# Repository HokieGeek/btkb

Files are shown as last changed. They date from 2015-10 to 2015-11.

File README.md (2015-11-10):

# btkb

I have a fantastic Pok3r mech that, annoyingly, uses a cable to connect to my computer. I am building a module that includes a decent battery and bluetooth modem to replace the cable.

## Prototype
Current

# Schematics
## Power module
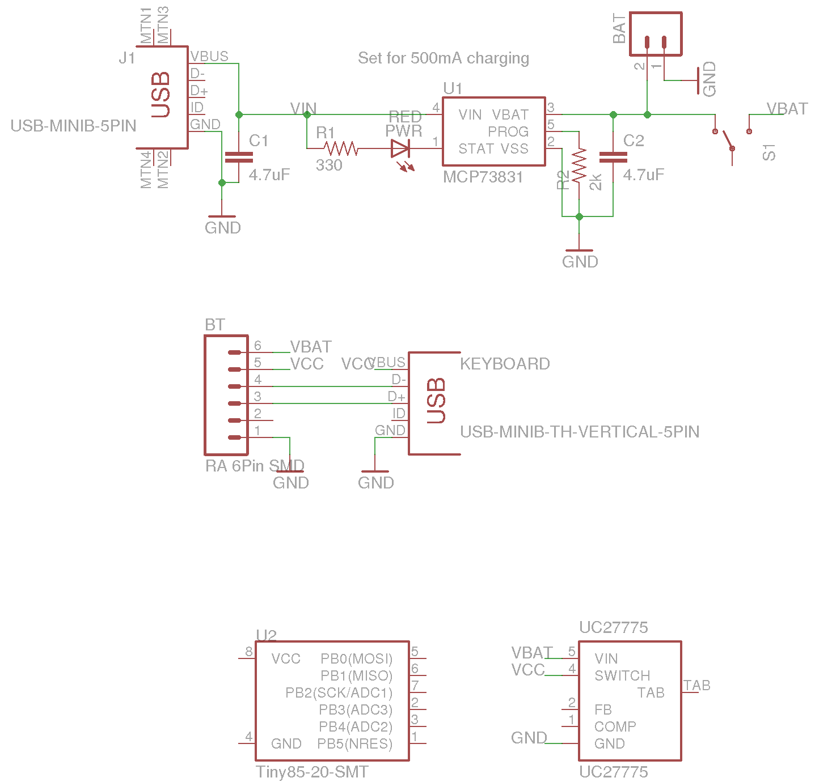
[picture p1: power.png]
Power module schematics

## Bluetooth module
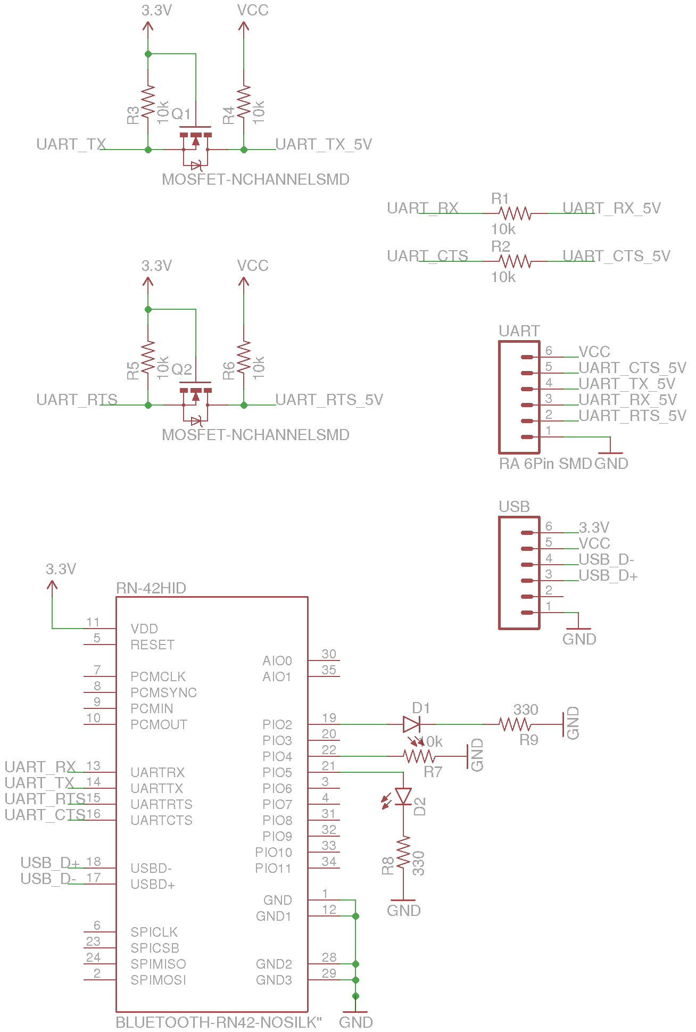
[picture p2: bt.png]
Bluetooth module schematics


# Board
## Power module
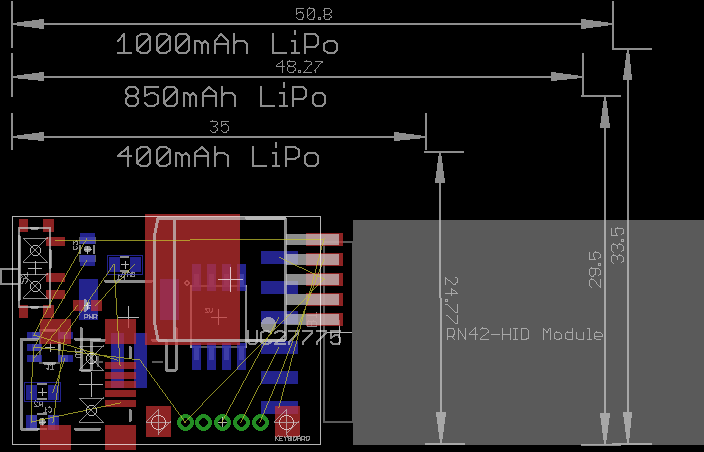
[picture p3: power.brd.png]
Power module board

## Bluetooth Module
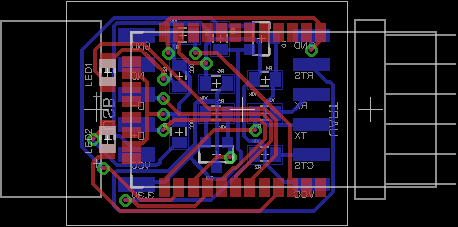
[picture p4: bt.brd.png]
Bluetooth module board


# Parts list
[Mouser project](https://www.mouser.com/ProjectManager/ProjectDetail.aspx?ProjectGUID=d7660f5c-4cd6-4143-9f81-287e7d12060d)

## ICs
- [RN-42 HID](http://www.sparkfun.com/datasheets/Wireless/Bluetooth/rn-42-ds.pdf) - Bluetooth modem with HID firmware
- [BSS138](https://www.fairchildsemi.com/datasheets/BS/BSS138.pdf) - MOSFET N-Channel Logic
- [MCP73831T](https://www.sparkfun.com/datasheets/Prototyping/Batteries/MCP73831T.pdf) - Li-Ion battery 4.5V voltage regulator
- [LM25775](http://www.ti.com/lit/ds/symlink/uc2577-adj.pdf) - Adjustable step-up voltage regulator

## Other components

* LEDs
 * 1x Red (data in to BT)
 * 1x Green (data out of BT)
 * Some sort of LED for battery status (TODO)
* Resistors
 * 7x 10 kΩ
 * 1x 2 kΩ
 * 3x 330 Ω
* Capacitors
 * 2x 10 µF (polarized)
 * 2x 4.7 µF
 * 2x 1 µF

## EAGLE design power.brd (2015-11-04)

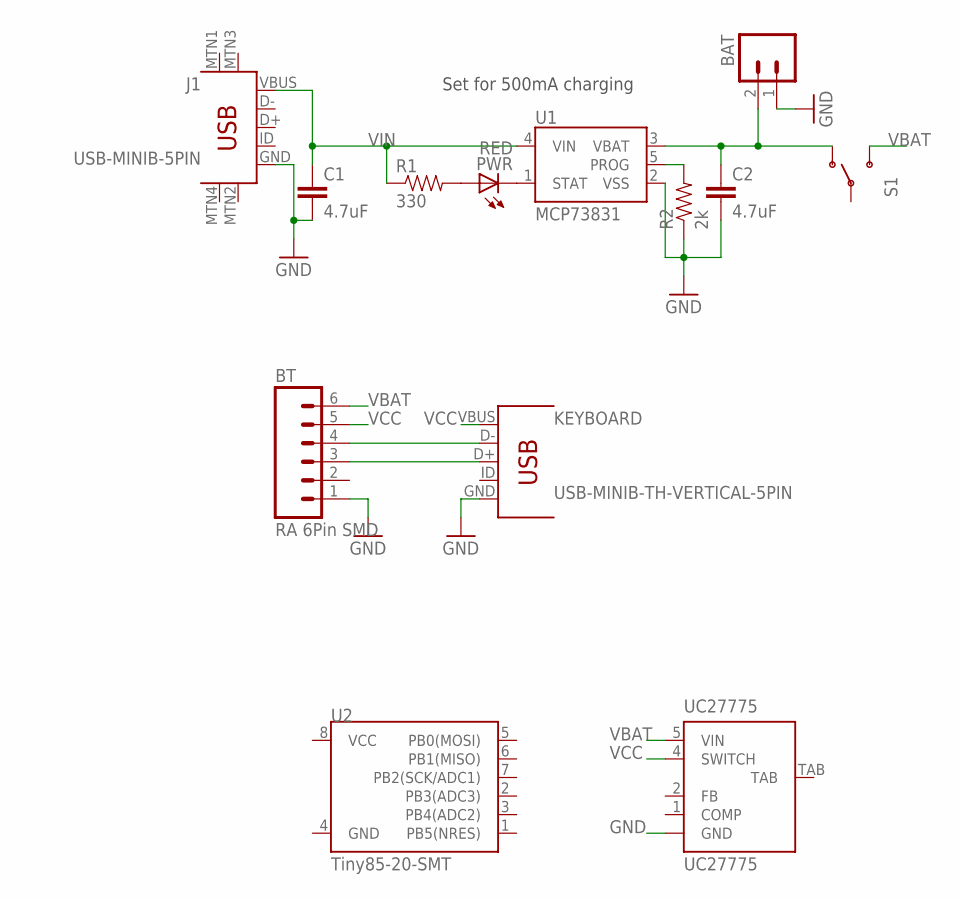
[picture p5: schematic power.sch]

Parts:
BAT: LiPo Battery; JST-2-SMD
BT: RA 6Pin SMD; 1X06-SMD-NOHOLES
C1, C2: 4.7uF; 0805-CAP
J1: USB-MINIB-5PIN; USB-MINIB
KEYBOARD: USB-MINIB-TH-VERTICAL-5PIN; USB-MINIB-TH-VERTICAL
PWR: RED; LED-0603
R1: 330; 0805
R2: 2k; 0805
S1: SWITCH-SPDT-SMD-A; SWITCH-SPST-SMD-A
U1: MCP73831; SOT23-5
U2: Tiny85-20-SMT; SO08-EIAJ
UC27775: UC27775; TO263_5

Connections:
GND: BAT.1, BT.1, C1.2, C2.2, J1.GND, KEYBOARD.GND, R2.1, U1.2 (VSS), UC27775.3 (GND)
unnamed: BT.4, KEYBOARD.D-
unnamed: BT.3, KEYBOARD.D+
unnamed: PWR.A, R1.2
PROG: R2.2, U1.5 (PROG)
STAT: PWR.C, U1.1 (STAT)
VBAT: BT.6, S1.3 (S), UC27775.5 (VIN)
VBAT2: BAT.2, C2.1, S1.1 (O), U1.3 (VBAT)
VCC: BT.5, KEYBOARD.VBUS, UC27775.4 (SWITCH)
VIN: C1.1, J1.VBUS, R1.1, U1.4 (VIN)

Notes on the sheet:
Set for 500mA charging

Board: 2 copper layers, 13 parts (8 on the bottom side), 10 nets, no tracks yet.

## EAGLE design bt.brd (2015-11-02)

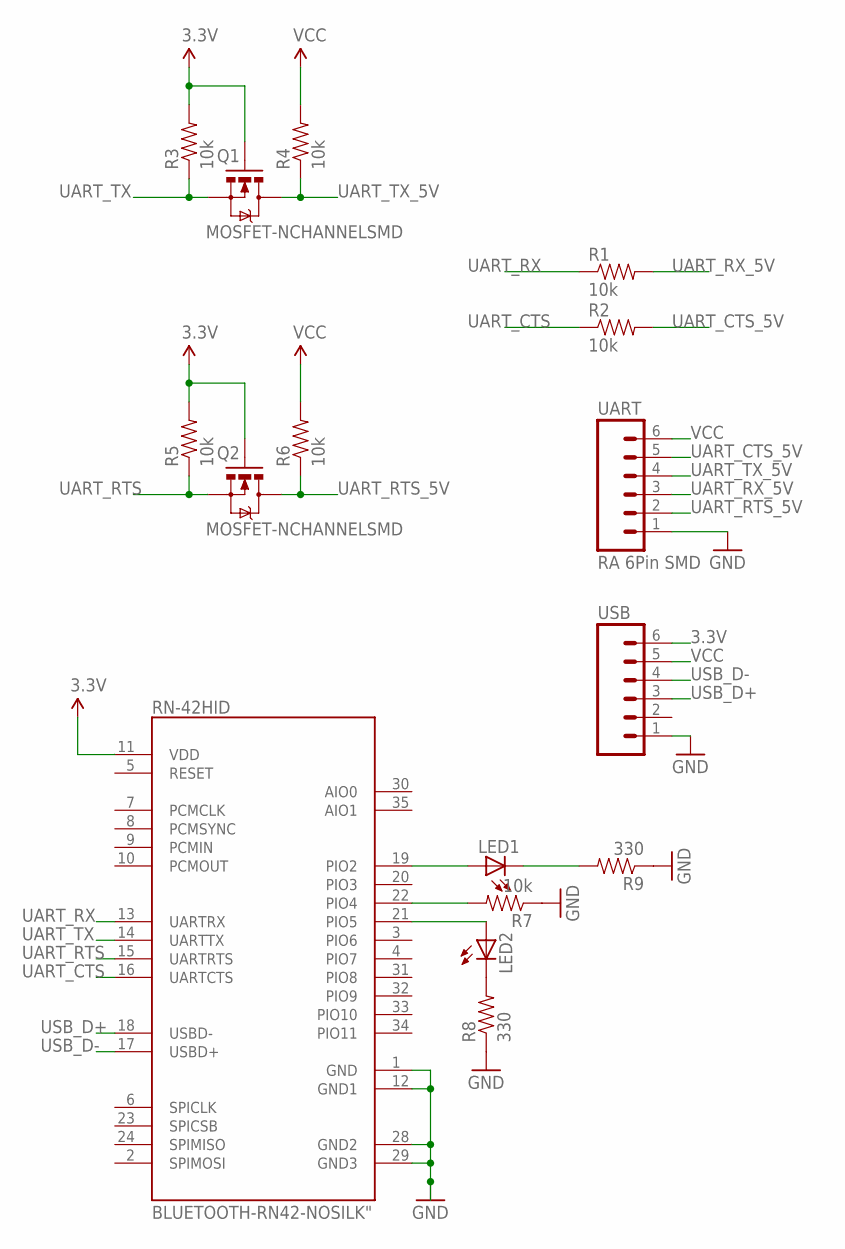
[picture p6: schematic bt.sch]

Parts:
LED1, LED2: LEDCHIP-LED0805; CHIP-LED0805
Q1, Q2: MOSFET-NCHANNELSMD; SOT23-3
R1, R2, R3, R4, R5, R6, R7: 10k; 0805
R8, R9: 330; 0805
RN-42HID: BLUETOOTH-RN42-NOSILK"; RN41
UART: RA 6Pin SMD; 1X06-SMD-NOHOLES
USB: M06SMD-FEMALE-V2-NOSILK; 1X06-SMD-FEMALE-V2-NOSILK

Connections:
3.3V: Q1.1 (G), Q2.1 (G), R3.2, R5.2, USB.6
GND: R7.1, R8.1, R9.1, RN-42HID.1 (GND), RN-42HID.12 (GND1), RN-42HID.28 (GND2), RN-42HID.29 (GND3), UART.1, USB.1
unnamed: LED2.C, R8.2
unnamed: LED1.C, R9.2
unnamed: LED1.A, RN-42HID.19 (PIO2)
unnamed: R7.2, RN-42HID.22 (PIO4)
unnamed: LED2.A, RN-42HID.21 (PIO5)
UART_CTS: R2.1, RN-42HID.16 (UARTCTS)
UART_CTS_5V: R2.2, UART.5
UART_RTS: Q2.2 (S), R5.1, RN-42HID.15 (UARTRTS)
UART_RTS_5V: Q2.3 (D), R6.1, UART.2
UART_RX: R1.1, RN-42HID.13 (UARTRX)
UART_RX_5V: R1.2, UART.3
UART_TX: Q1.2 (S), R3.1, RN-42HID.14 (UARTTX)
UART_TX_5V: Q1.3 (D), R4.1, UART.4
USB_D+: RN-42HID.18 (USBD-), USB.3
USB_D-: RN-42HID.17 (USBD+), USB.4
VCC: R4.2, R6.2, RN-42HID.11 (VDD), UART.6, USB.5

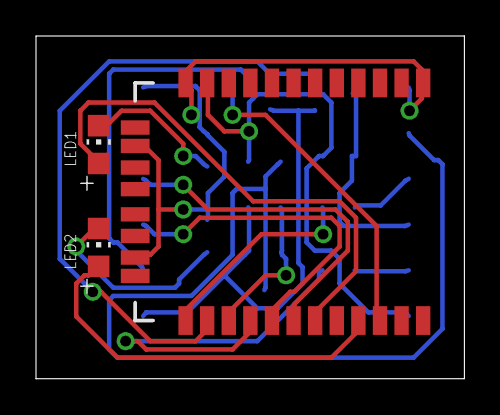
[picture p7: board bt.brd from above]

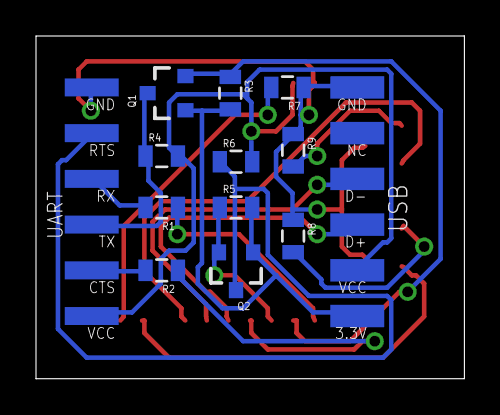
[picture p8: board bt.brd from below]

Board: 2 copper layers, 23.8 x 19.0 mm, 16 parts (13 on the bottom side), 18 nets.

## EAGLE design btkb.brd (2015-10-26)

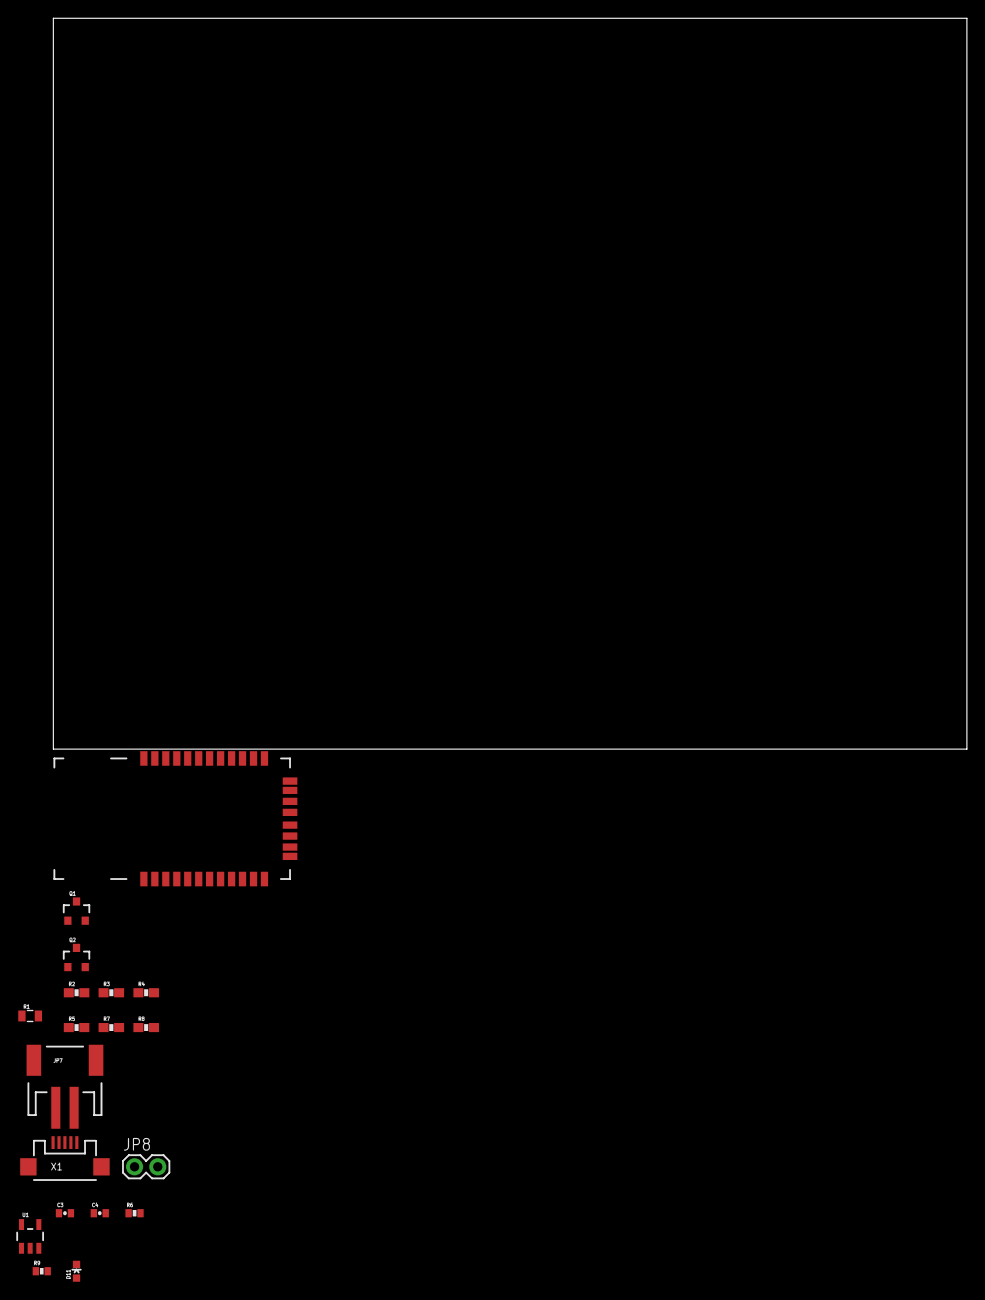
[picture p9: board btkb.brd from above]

Board: 2 copper layers, 100.0 x 80.0 mm, 19 parts (0 on the bottom side), 11 nets, no tracks yet.

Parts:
C3, C4: 4.7uF; 0402-CAP
D11: RED; LED-0603
IC1: BLUETOOTH-RN42 HID; RN41
JP7: LiPo Battery; JST-2-SMD
JP8: 1X02
Q1, Q2: MOSFET-NCHANNELSMD; SOT23-3
R1: 10k; 0805
R2, R3, R4, R5, R7, R8: 10K; 0603-RES
R6: 330; 0402-RES
R9: 2K; 0402-RES
U1: MCP73831; SOT23-5
X1: Micro USB; USB-MICROB

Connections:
3.3V: Q1.1, Q2.1, R3.1, R7.1
GND: C3.2, C4.2, IC1.1, IC1.12, IC1.28, IC1.29, JP7.1, JP8.1, R9.2, U1.2, X1.GND
unnamed: D11.A, R6.1
PROG: R9.1, U1.5
RTS: Q2.2, R7.2
RTS_5V: Q2.3, R8.2
STAT: D11.C, U1.1
TX: Q1.2, R3.2
TX_5V: Q1.3, R4.2
VCC: C4.1, JP7.2, JP8.2, R4.1, R8.1, U1.3
VIN: C3.1, R6.2, U1.4, X1.VBUS

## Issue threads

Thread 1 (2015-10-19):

References

HokieGeek, 2015-10-19:
RN42 HID circuit: https://www.sparkfun.com/products/10938
Basic lipo charger: https://www.sparkfun.com/products/10217
Lipo fuel gauge: https://www.sparkfun.com/products/10617
Boost battery power: https://www.adafruit.com/products/1903

HokieGeek, 2015-10-28:
Maybe a different boost converter? I don't necessarily need something that solves all problems evar. (Although having the battery gauge along with the TPS is nice...)

LT1302CN8-5

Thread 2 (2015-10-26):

Use attiny for battery gauge

HokieGeek, 2015-10-26:
http://wp.josh.com/2014/11/06/battery-fuel-guage-with-zero-parts-and-zero-pins-on-avr/
http://www.instructables.com/id/Arduino-ATTiny85-Voltage-Monitor-RGB-LED/
http://electronics.stackexchange.com/questions/154523/attiny85-measuring-internal-voltage

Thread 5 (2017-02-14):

How mature is this

marcodejongh, 2017-02-14:
Hey HokieGeek,

Nice job on this project and all the diagrams, I was just wondering how mature is the project?
Do you have photos or more information on your end product? My biggest complaint about my pok3r is it not being wireless, so I'd be very keen to make mine wireless

HokieGeek, 2017-03-28:
Not very. The only way I could make the design work with the size I wanted was with a 4 layer PCB which I do not wish to pay for :). So I mostly dropped this effort.

Closed 2017-03-28.

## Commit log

2015-10-13 Adding the placeholder files
    [btkb.brd, btkb.sch]
2015-10-14 I added the RN-42 to the schematic! lol!
    [btkb.brd, btkb.sch]
2015-10-26 No battery gauge and fixing rn42 datasheet
2015-10-26 Added components copy pasta'ed from other schematics
    [btkb.brd]
2015-10-26 Updated component list
    Still doesn't include the boost circuit
2015-10-28 Starting to flesh this out
    [bt.brd, bt.sch, power.brd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]
2015-10-28 Updating with changes
    [bt.sch]
2015-10-29 More updates
    [power.sch]
2015-10-30 Tried to route the BT board.... Do I need 4 layers for this?
    [bt.brd, power.brd, power.sch]
2015-10-30 Updated headers to remove annoying holes and now using my own library
    [power.sch]
2015-10-30 Updated height of board to match bt board and rearranged components
    [power.brd]
2015-10-30 Removed silk from bt module and renamed headers
    [bt.sch]
2015-10-30 Flipped the board around
    [bt.brd]
2015-10-30 Putting more info on this thing to help me out
    [power.sch]
2015-10-30 Changing which pins are the USB data pins to match the standard
    [bt.sch]
2015-11-02 Got a good handle on the bt module so went ahead and ordered one
    [bt.brd, bt.sch, power.brd]
2015-11-02 Added prototype pic
2015-11-02 Added a switch and cleaned up the drawings
    [power.sch]
2015-11-02 Added a switch and playing around with the arrangement
    [power.brd]
2015-11-04 Using mini usb instead of micro
    [power.brd, power.sch]

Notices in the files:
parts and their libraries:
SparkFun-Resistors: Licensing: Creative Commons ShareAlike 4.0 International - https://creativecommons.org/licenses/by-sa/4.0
